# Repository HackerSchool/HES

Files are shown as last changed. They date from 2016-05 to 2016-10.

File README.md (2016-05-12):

HES (Hacker Entertainment System)
=================================

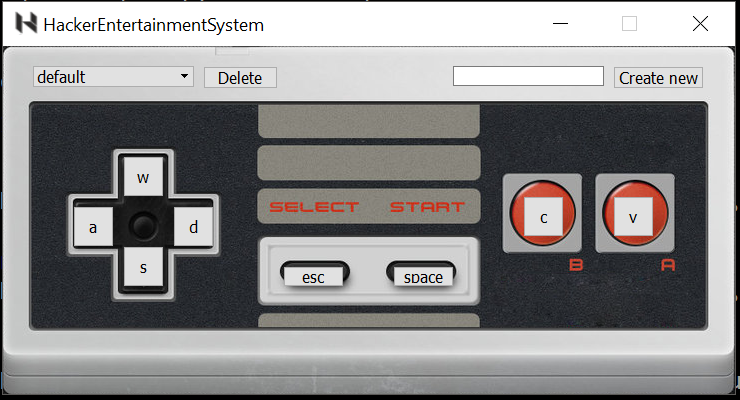
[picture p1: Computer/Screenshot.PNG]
DriverGUI Screenshot of the gui for the driver


### Setting up the controller
Simply program your arduino with the code on the Arduino folder

### Running the driver
Make sure you have Python 3.5 and PyQT 5.6 installed, as well as pip install Pillow, PyAutoGui and PySerial.

This project is structured as a Python Package so instead of running `python3 file.py` you should, from the HES folder, run `python3 -m Computer` (or `python -m Computer`, if python 3 is your default python installation)
> Note: The Computer/gui and Computer/driver folders are set up as packages themselves, so if you just want to test the GUI or the driver by itself you can run `python3 -m Computer.gui` or `python3 -m Computer.driver`

### Why a Python package?
Using a Python Package allows us to use absolute imports instead of relative ones, which can be useful in many situations.
You can read more about it here: https://docs.python.org/3/tutorial/modules.html#packages

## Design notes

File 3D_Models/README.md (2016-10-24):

You can see the 3D models [here](https://cad.onshape.com/documents/5ac885e8e6d6d81ccd5e2858/w/fee59fdc9be4ca5cda2cbde7/e/3afd5cdb7876b395a9ed1bcb)

After creating an Onshape account you can export the files using the method seen [here](https://cad.onshape.com/help/Content/downloadfiles.htm)

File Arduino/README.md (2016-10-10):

### Pinouts
##### Mark I (Amêndoa)
```
#define GND1 4
#define GND2 14
#define GND3 15

#define SELECT 7
#define START 12
#define UP 18
#define DOWN 2
#define LEFT 17  
#define RIGHT 19
#define A 11
#define B 6

#define LED 13
```

##### Mark II (Mariana)
```
#define GND1 6
#define GND2 6
#define GND3 19

#define SELECT 5
#define START 4
#define UP 16
#define DOWN 18
#define LEFT 15
#define RIGHT 17
#define A 12
#define B 8

#define LED 10
```
##### Mark III (PCB V1)
```
#define GND1 4
#define GND2 15
#define GND3 11

#define SELECT 12
#define START 8
#define UP 14
#define DOWN 18
#define LEFT 16
#define RIGHT 17
#define A 7
#define B 6

#define LED 10
```
##### Mark IV (PCB V2)
```
#define GND1 4
#define GND2 15
#define GND3 11

#define SELECT 12
#define START 7
#define UP 14
#define DOWN 18
#define LEFT 16
#define RIGHT 17
#define A 19
#define B 5

#define LED 10
```

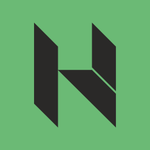
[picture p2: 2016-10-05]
PCB/board/images/HackerSchool.png

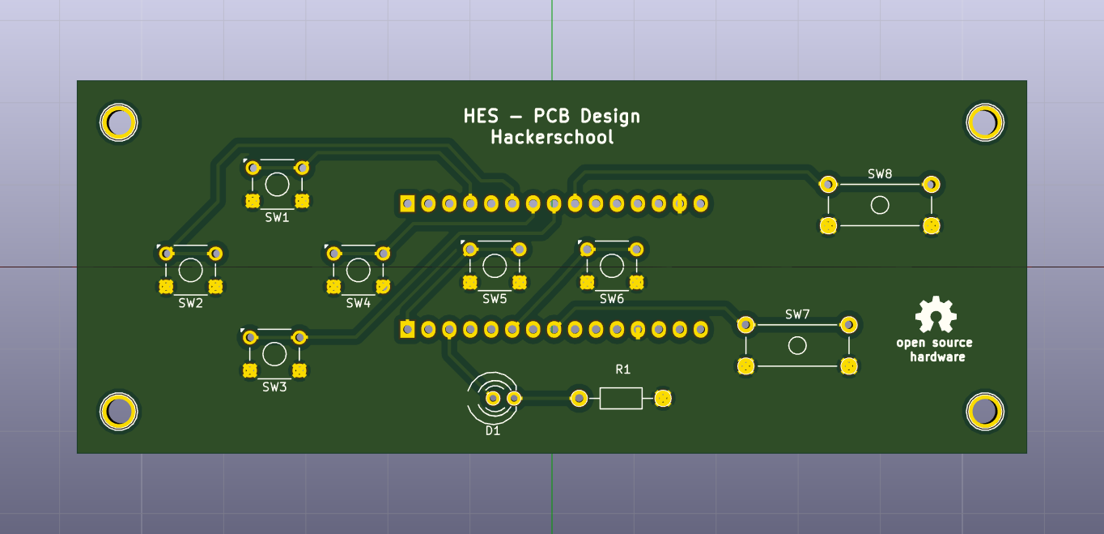
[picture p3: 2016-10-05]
PCB/board/hes_open.png

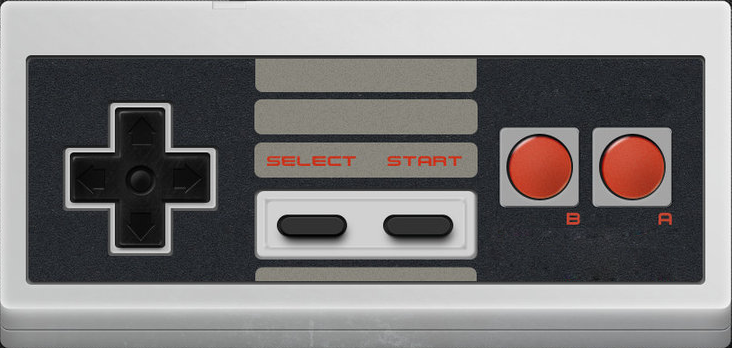
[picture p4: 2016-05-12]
Computer/resources/HES_front.png

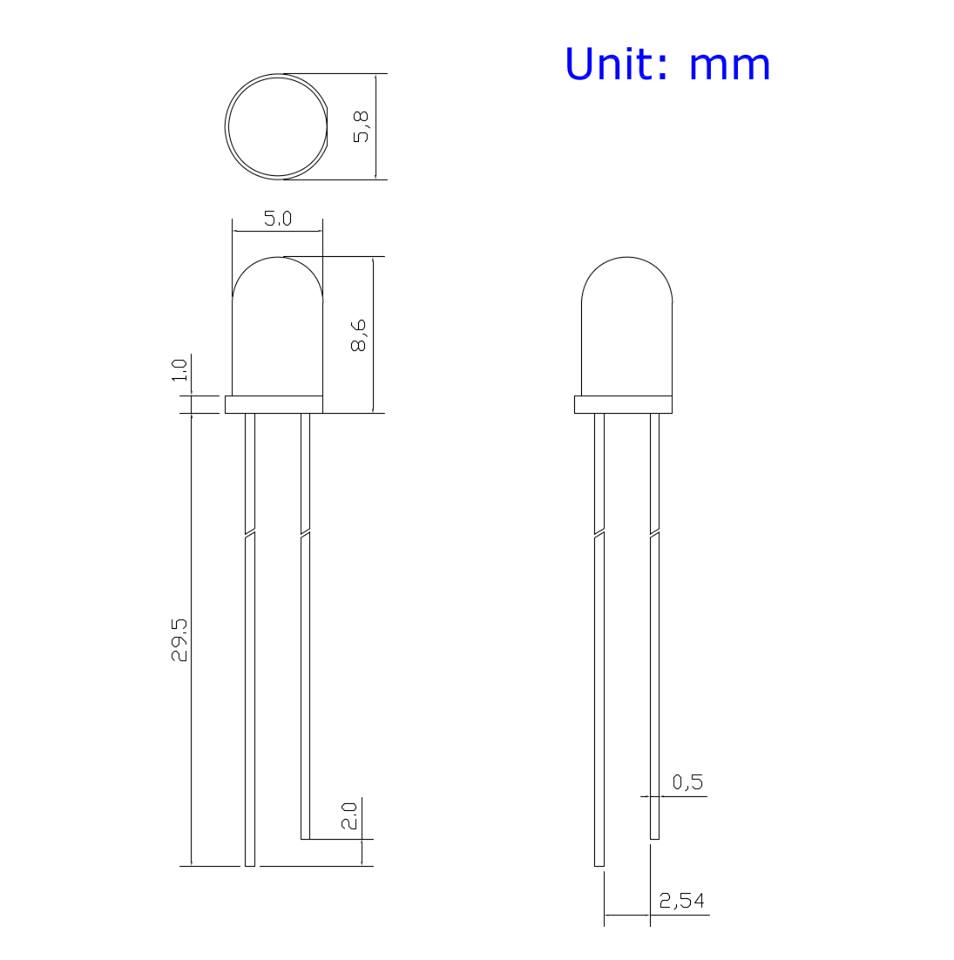
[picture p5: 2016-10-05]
PCB/datasheets/led.png

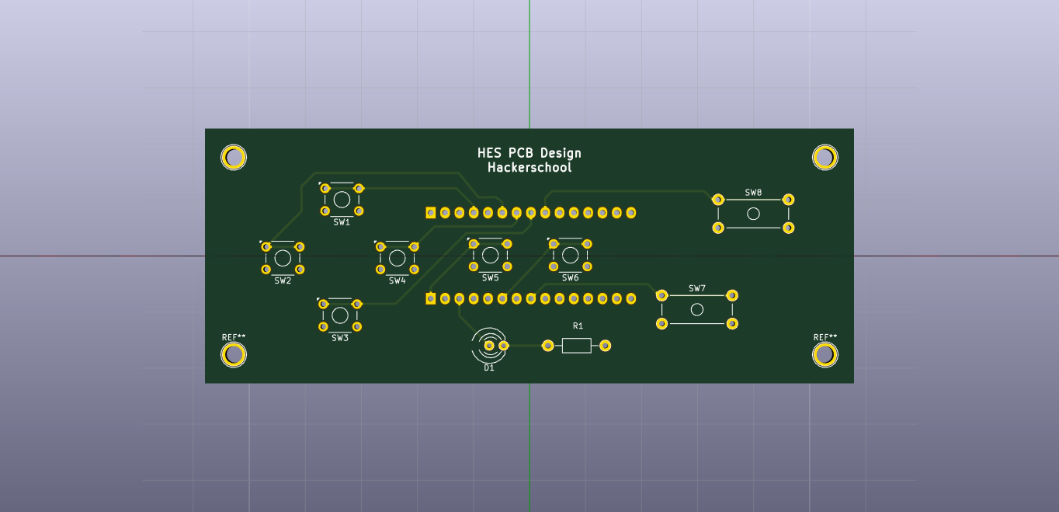
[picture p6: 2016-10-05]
PCB/board/hes.png

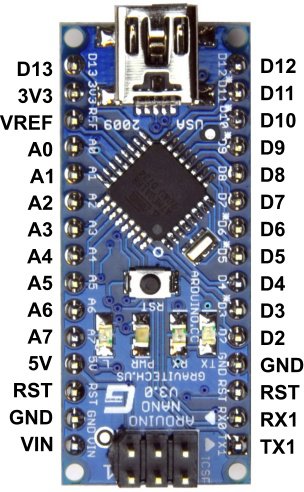
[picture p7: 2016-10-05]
PCB/datasheets/arduino_nano.jpg

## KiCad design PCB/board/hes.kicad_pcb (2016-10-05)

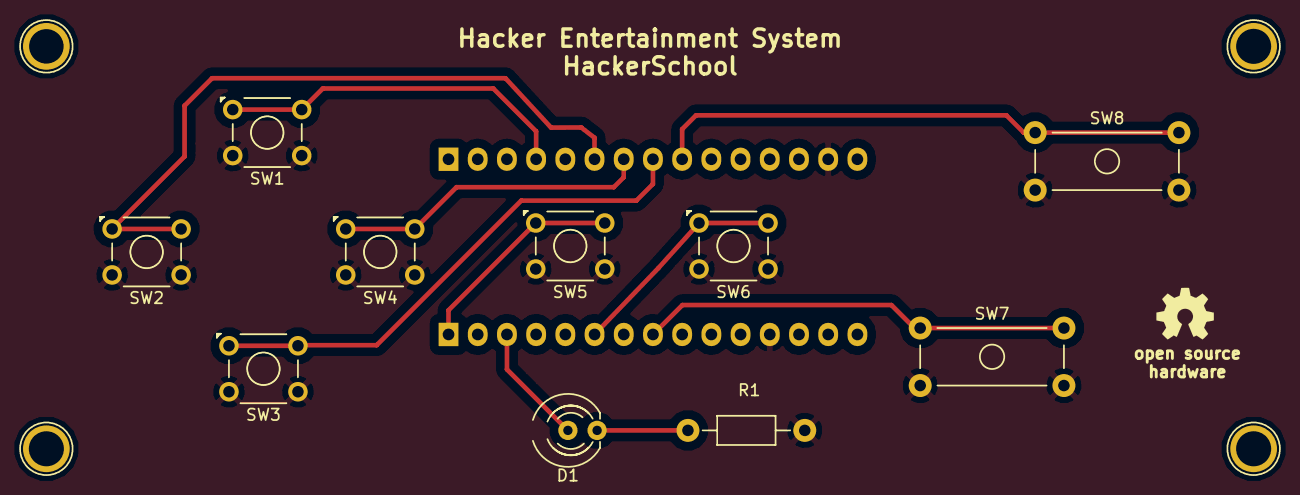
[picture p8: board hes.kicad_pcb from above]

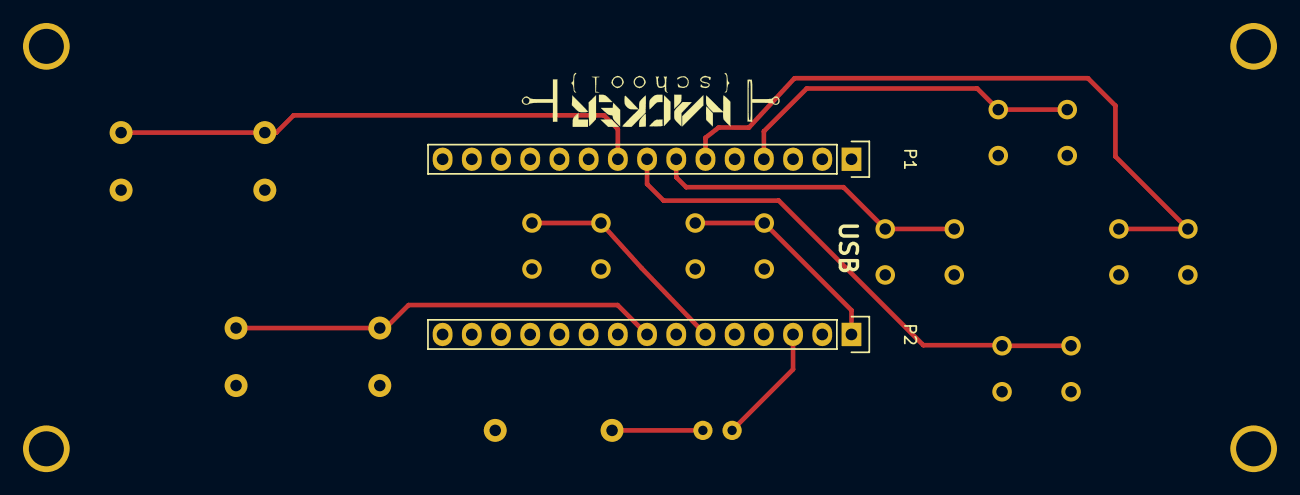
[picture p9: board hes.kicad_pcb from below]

Board: 2 copper layers, 12 parts (2 on the bottom side), 11 nets.

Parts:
D1: LED; LED-5MM-3
P1, P2: CONN_01X15; Pin_Header_Straight_1x15
R1: Resistor; Resistor_Horizontal_RM10mm
SW1, SW2, SW3, SW4, SW5, SW6: SW_PUSH; SW_TH_Tactile_Omron_B3F-10xx
SW7, SW8: SW_PUSH; B3F-4000

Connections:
/A: P1.9, SW8.1
/B: P2.8, SW7.1
/D: P1.8, SW3.1, SW3.2
/L: P1.4, SW1.1
/LED: D1.2, P2.3
/R: P1.7, SW4.1, SW4.2
/SL: P2.1, SW5.1, SW5.2
/ST: P2.6, SW6.1, SW6.2
/U: P1.6, SW2.1
GND: P1.14, P2.12, R1.2, SW1.3, SW1.4, SW2.3, SW2.4, SW3.3, SW3.4, SW4.3, SW4.4, SW5.3, SW5.4, SW6.3, SW6.4, SW7.2, SW8.2
unnamed: D1.1, R1.1

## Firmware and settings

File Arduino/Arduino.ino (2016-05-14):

#define DEBOUNCE 8 // (ms) half a frame at 60Hz
#define PRESSEDLOGICLEVEL LOW

#define GND1 4
#define GND2 15
#define GND3 11

#define SELECT 12
#define START 8
#define UP 14
#define DOWN 18
#define LEFT 16 
#define RIGHT 17
#define A 7
#define B 6

#define LED 10

byte buttons[] = {SELECT, START, UP, DOWN, LEFT, RIGHT, A, B}; // the analog 0-5 pins are also known as 14-19
#define NUMBUTTONS sizeof(buttons)

// we will track if a button is just pressed, just released, or 'currently pressed'
volatile byte pressed[NUMBUTTONS], justpressed[NUMBUTTONS], justreleased[NUMBUTTONS]; 

void setup() {
    // initialize serial communication at 9600 bits per second:
    Serial.begin(9600);

    pinMode(GND1, OUTPUT);
    pinMode(GND2, OUTPUT);
    pinMode(GND3, OUTPUT);
    digitalWrite(GND1, LOW);
    digitalWrite(GND2, LOW);
    digitalWrite(GND3, LOW);

    for (byte i=0; i < NUMBUTTONS; i++)
        pinMode(buttons[i], INPUT_PULLUP);

    pinMode(LED, OUTPUT);
    digitalWrite(LED, LOW);

    while(!Serial.available())
    {
        String challenge = Serial.readString();
        if (challenge == "Hi. Who are you?")
        {
            Serial.write("Hi. I'm HES.\n");
            break;
        }
        delay(100);
    }

    // Run timer2 interrupt every 15 ms
    TCCR2A = 0;
    TCCR2B = 1<<CS22 | 1<<CS21 | 1<<CS20;

    //Timer2 Overflow Interrupt Enable
    TIMSK2 |= 1<<TOIE2;

    digitalWrite(LED, HIGH);
}


void check_switches()
{
    static byte previousstate[NUMBUTTONS];
    static byte currentstate[NUMBUTTONS];
    static long lasttime;
    byte index;
  
    if (millis() < lasttime){ 
        lasttime = millis(); // we wrapped around, lets just try again
    }
   
    if (millis() < (lasttime + DEBOUNCE)) {
        return; // not enough time has passed to debounce
    }
    
    lasttime = millis(); // ok we have waited DEBOUNCE milliseconds, lets reset the timer
   
    for (index = 0; index < NUMBUTTONS; index++)
    {
        currentstate[index] = digitalRead(buttons[index]);   // read the button
       
        if (currentstate[index] != previousstate[index]) // state changed after the debounce delay
        {
          if (!pressed[index] && (currentstate[index] == PRESSEDLOGICLEVEL)) {              
              justpressed[index] = 1; // just pressed
          }
          else if (pressed[index] && (currentstate[index] == !PRESSEDLOGICLEVEL)) {              
              justreleased[index] = 1; // just released
          }
          
          if (PRESSEDLOGICLEVEL == HIGH) 
            pressed[index] = currentstate[index];   
          else 
            pressed[index] = !currentstate[index]; // the 'pressed' byte array uses HIGH to mean pressed 
        }
        previousstate[index] = currentstate[index];   // keep a running tally of the buttons
    }
}


SIGNAL(TIMER2_OVF_vect) {
  check_switches();
}


void loop()
{       
    for (byte i = 0; i < NUMBUTTONS; i++){
        if (justpressed[i]) {
            justpressed[i] = 0;
            Serial.print("P");
            Serial.println(i);            
        }
        if (justreleased[i]) {
            justreleased[i] = 0;
            Serial.print("R");
            Serial.println(i);
            
        }
        /*if (pressed[i]) {
            Serial.print(i, DEC);
            Serial.println(" pressed");
            // is the button pressed down at this moment
        }*/      
    }
    delay(1);
}

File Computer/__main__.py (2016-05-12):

# Internal
import Computer.driver.driver_main as driver
import Computer.gui.edit_bindings_gui as gui
import Computer.settings as settings
from Computer.driver.button_bindings import ButtonBindings


button_bindings = ButtonBindings()  # instantiate the button bindings object
# by modifying this object you can change what keys are activated when pressing the buttons

driver_thread = driver.DriverThread(button_bindings)  # create a driver thread and pass it the bindings object

driver_thread.daemon = True if settings.gui else False
# Python terminates the program when only Daemon threads exist.
# We want the program to terminate when the user closes the main (gui) thread, so the driver is set as a Daemon

driver_thread.start()

if settings.gui:
    gui.run_gui(button_bindings)  # pass the bindings object to the gui as well

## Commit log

2016-02-07 Improves arduino code. Key diff with debounce
2016-02-07 Arduino manipulates keyboard
    Select (PIND.1) does not work properly because it interferes with the TX
    pin (they are the same pin).
    [controller_communication.py]
2016-02-11 Added ground pins
2016-02-28 implemented binding profiles for the buttons and started working on the GUI
    [Arduino.ino, button_bindings.py, settings.py]
2016-05-05 bindings modification done
    - also changed profile management a bit
    [button_bindings.py, settings.py]
2016-05-08 GUI integrated with the driver. Needs cleanup and testing.
2016-05-12 Fixed the libpng warning and made Computer.gui a package itself
    libpng was complaining about the image format
    [__main__.py]
2016-05-12 Made Computer.driver runnable as a package
2016-05-14 Update Arduino.ino
    update pinout
2016-10-05 Added the PCB files
    [hes-B.Cu.gbl, hes-B.Mask.gbs, hes-B.Paste.gbp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]
2016-10-07 Update README.md
    Add pinout PCB v2
